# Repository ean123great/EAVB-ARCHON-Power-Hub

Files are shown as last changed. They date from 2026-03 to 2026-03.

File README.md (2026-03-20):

# EAVB ARCHON 15W Power Hub
**High-Efficiency DC-DC Step-Down Architecture with PMOS Protection**

Designed by **Elcyn Andrew V. Booc** | EAVB Electronics



The **ARCHON Power Hub** is a compact, industrial-grade power management module designed for autonomous robotics, IoT systems, and high-reliability embedded environments. Utilizing a 1.5 MHz switching frequency and the proprietary "Ocean Ground Strategy," ARCHON delivers up to 15W of continuous power with exceptional thermal stability and minimal EMI.

---

### Key Architectural Features
* **Zero-Drop Reverse Polarity Protection:** Utilizes an AO4407A P-Channel MOSFET instead of a standard Schottky diode, eliminating thermal dissipation and voltage drop at the input stage.
* **The "Ocean Ground Strategy":** A highly optimized SMD PCB layout utilizing extensive ground pours and thermal via stitching to turn the entire FR4 board into a passive heatsink.
* **High-Frequency Regulation:** Driven by the MP1584EN switching regulator operating at 1.5 MHz, allowing for extreme component density and rapid transient response.
* **Industrial Form Factor:** Exclusively utilizes Surface Mount Devices (SMD), including 0805 passives and SOIC-8 packaging, for a manufacturing-ready footprint.

---

### Absolute Maximum Ratings & Specifications

| Parameter | Specification | Notes |
| :--- | :--- | :--- |
| **Input Voltage Range** | 4.5V to 28V DC | Regulated |
| **Output Voltage** | 5.0V (Adjustable) | Tuned via precision resistor network |
| **Max Continuous Current** | 3A | Requires adequate airflow at max load |
| **Maximum Power Output** | 15W | |
| **Peak Efficiency ($\eta$)** | Up to 92% | Load dependent |
| **Switching Frequency** | 1.5 MHz | Reduces inductor size requirement |

---

### Repository Structure
* `/Hardware` - KiCad schematic (`.kicad_sch`), PCB layout (`.kicad_pcb`), and manufacturing Gerber files.
* `/Docs` - Official EAVB technical specifications, absolute maximum ratings, and theory of operation (PDF).

---

### Intellectual Property & Commercial Licensing
This hardware design is protected under the **CC BY-NC-SA 4.0** license. 
* **Non-Commercial Use:** Students, hobbyists, and researchers are free to study, build, and modify this architecture for personal or academic use, provided credit is given to **EAVB Electronics**.
* **Commercial Use:** Manufacturing this board for sale or integrating this architecture into a commercial product is strictly prohibited under this license.

> **For Commercial Manufacturing Rights:** > Please contact the Lead Architect at **eavb.electronics@gmail.com** for corporate licensing agreements.

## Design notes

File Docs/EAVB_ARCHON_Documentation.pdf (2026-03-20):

EAVB Electronics (2026) | ARCHON 15W HUB | Version 1.0
Document v1.0 | Elcyn Andrew V. Booc | March 2026

# ARCHON 15W POWER HUB: High-Efficiency DC-DC Converter & Distribution Node

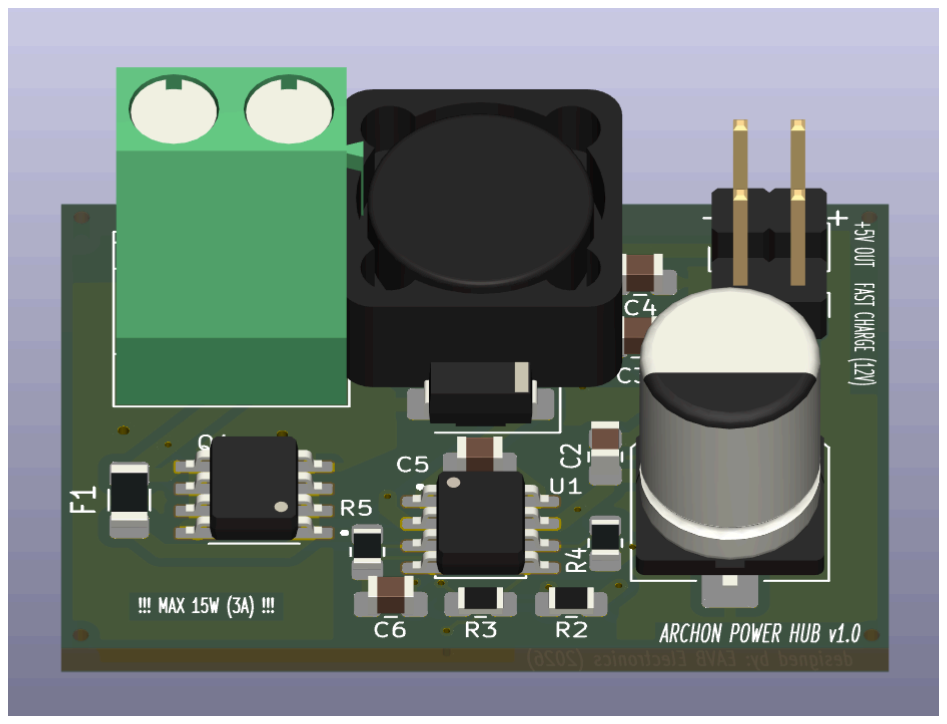
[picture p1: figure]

## GENERAL DESCRIPTION

The Archon Power Hub is a robust, high-efficiency synchronous switch-mode DC-DC step-down converter designed for precision voltage regulation and hardware protection. Centered around the MP1584EN high-frequency switching architecture, the Archon seamlessly steps down a 12V DC input to a heavily filtered, stable 5V output. Featuring hardware-level PMOS reverse-polarity shielding and a heavy copper thermal ground plane, the Archon delivers clean, low-noise power optimized for sensitive embedded electronics, microcontrollers, and prototyping environments.

## KEY FEATURES

- Optimized Power Delivery: 5V output at up to 3.0A continuous current (15W).
- Wide Input Range: 7.0V to 12.0V DC operational input.
- Hardware-Level Protection: Integrated P-Channel MOSFET (Q1) and Fuse (F1) for zero-drop reverse polarity and overcurrent protection.
- High-Frequency Switching: ~1.5 MHz programmable switching frequency minimizing external component size.
- Ultra-Low Ripple: Dual-stage parallel ceramic output filtering (C3, C4) for superior transient response.
- Versatile Distribution: Dual USB Type-C module headers and auxiliary Dupont outputs.
Document v1.0 | ARCHON 15W HUB | Page 1

## Electrical Characteristics & Ratings

Parameter | Symbol | Min | Typ | Max | Unit

ABSOLUTE MAXIMUM RATINGS

Input Supply Voltage | VIN | -0.3 | -- | 15.0 | V
Enable Pin Voltage | VEN | -0.3 | -- | 6.0 | V
Switch Node Voltage | VSW | -0.3 | -- | VIN + 0.3 | V
Maximum Junction Temperature | TJ(MAX) | -- | -- | 150 | °C
Storage Temperature Range | TSTG | -65 | -- | 150 | °C
RECOMMENDED OPERATING CONDITIONS
Input Operating Range | VIN | 7.0 | 12.0 | 12.0 | V
Regulated Output Voltage | VOUT | 4.90 | 5.00 | 5.10 | V
Continuous Output Current | IOUT | 0 | -- | 3.0 | A
Switching Frequency | fSW | -- | 1.5 | -- | MHz
Operating Ambient Temperature | TA | -40 | 25 | 85 | °C
SYSTEM PERFORMANCE & THERMAL
Quiescent Current (No Load) | IQ | -- | 1.0 | 1.5 | mA
Conversion Efficiency (VIN=12V, 2A) | η | -- | 92 | -- | %
Output Voltage Ripple | VRIPPLE | -- | 30 | 50 | mV
Thermal Resistance (Junction-to-Ambient) | θJA | -- | 50.0 | -- | °C/W
Document v1.0 | ARCHON 15W HUB | Page 2

## SYSTEM ARCHITECTURE & THEORY OF OPERATION

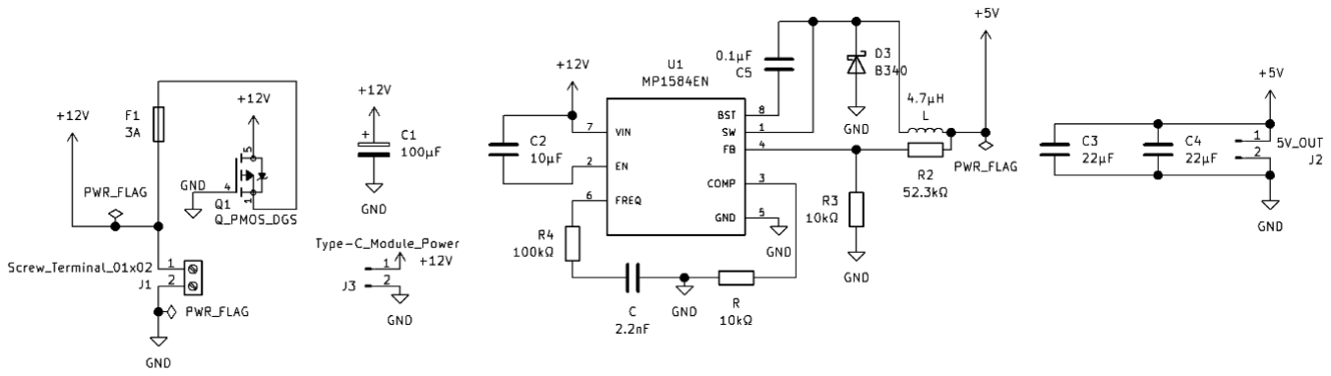
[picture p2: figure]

### 1. Input Protection Stage

Power enters via the J1 screw terminal and immediately passes through an overcurrent fuse (F1) and a P-Channel MOSFET (Q1). Unlike a standard blocking diode which wastes power through forward voltage drop, Q1 is configured as a low-RDS(on) reverse-polarity shield. If a power source is connected with reversed polarity, the gate-to-source voltage is neutralized, driving the PMOS into strict cut-off. This creates an immediate open circuit, protecting all downstream components with near-zero thermal loss during normal operation.

### 2. High-Frequency Step-Down Conversion

The core regulation is handled by U1 (MP1584EN). By utilizing a high switching frequency, the converter maintains greater than 90% efficiency while allowing the use of a highly compact 4.7µH surface-mount inductor (L2). The output voltage is strictly clamped to 5.0V via the precision feedback resistor network (R2, R3), which constantly samples the output node to dynamically adjust the internal duty cycle.

### 3. Switch Node & EMI Mitigation

To minimize electromagnetic interference (EMI), the "hot loop" comprising the U1 switch pin, inductor L2, and the Schottky catch diode (D3) is physically condensed. Trace lengths within this switching node are kept microscopic to reduce parasitic inductance and prevent the traces from acting as RF antennas.

### 4. Output Filtering & Distribution

Output power stability is guaranteed by placing two ceramic capacitors (C3 and C4) in parallel directly at the 5V output net. This parallel configuration drastically lowers the Equivalent Series Resistance (ESR) and Equivalent Series Inductance (ESL), acting as a high-speed shock absorber for high-frequency voltage ripples before the power is distributed to the Type-C and auxiliary headers.

Document v1.0 | ARCHON 15W HUB | Page 3

## PCB LAYOUT & THERMAL MANAGEMENT

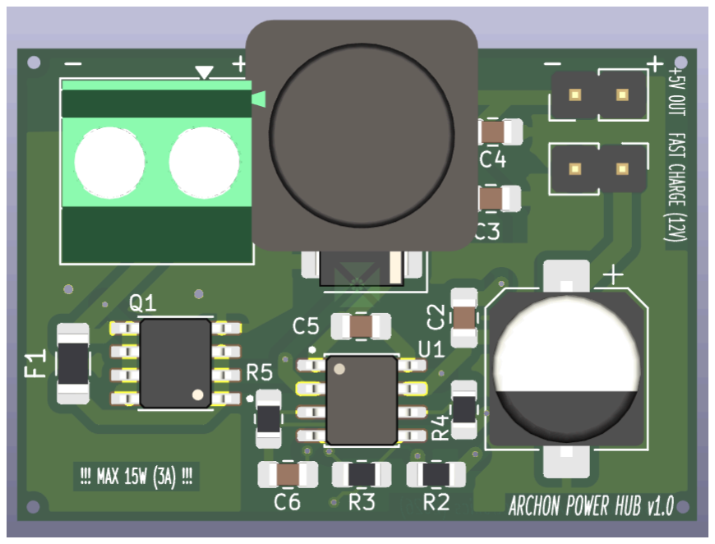
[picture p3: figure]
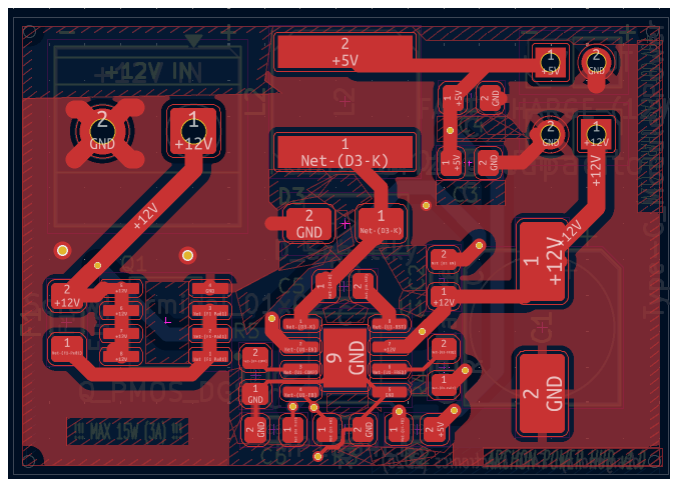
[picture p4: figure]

### 1. The Ocean Ground Strategy

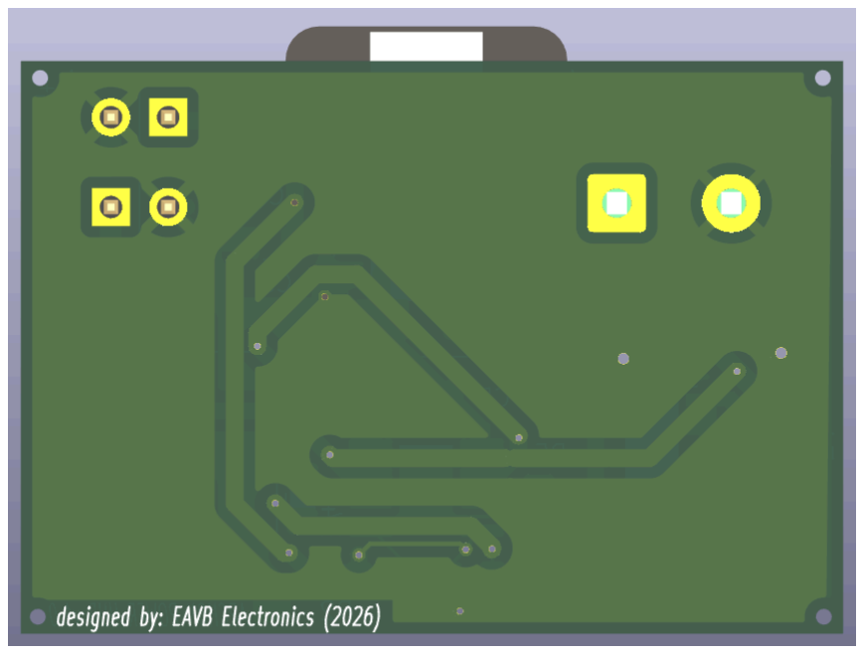
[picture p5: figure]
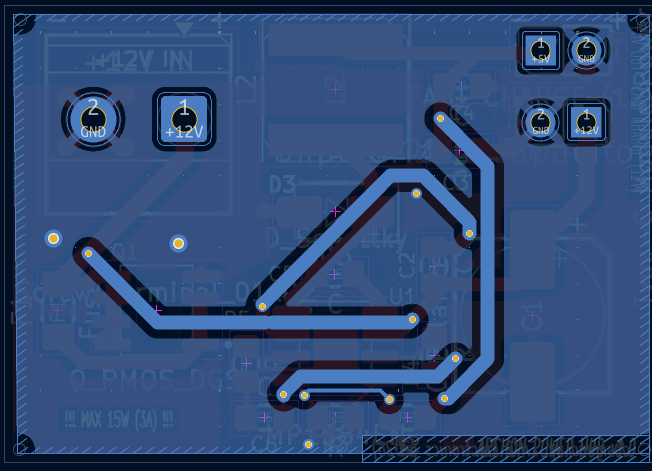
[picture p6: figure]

The Archon utilizes a continuous bottom-layer copper pour connected to the primary Ground net. This uninterrupted plane serves a dual purpose: it acts as a low-impedance return path for high-frequency switching currents (reducing ground bounce), and it functions as a massive passive heatsink.

### 2. Thermal Vias

To prevent thermal throttling within the MP1584EN silicon during continuous 3A loads, multiple thermal vias are stitched directly adjacent to the IC and inductor pads. These vias bridge the top-layer heat generators directly to the bottom "ocean" ground plane, radiating heat safely across the 75x50mm FR4 fiberglass substrate.

### 3. High-Current Routing

All primary power paths (VIN, Switch Node, and VOUT) are routed using oversized 0.8mm to 1.0mm copper traces. This exceeds standard ampacity requirements, ensuring minimal resistive voltage drops and virtually eliminating trace heating under peak load conditions.

Document v1.0 | ARCHON 15W HUB | Page 4

## Bill of Materials

Designator | Component Description | Value / Specification | Qty
U1 | High-Frequency Synchronous Buck Converter | MP1584EN | 1
Q1 | P-Channel Power MOSFET | AO4407A | 1
D3 | Schottky Barrier Rectifier Diode | B340 (3A, 40V) | 1
L2 | Shielded SMD Power Inductor | 4.7µH | 1
F1 | SMD Overcurrent Protection Fuse | 3.0A Fast Blow | 1
C1 | Electrolytic Input Filter Capacitor | 100µF (25V) | 1
C2 | Ceramic Input Bypass Capacitor (MLCC) | 10µF | 1
C3, C4 | Ceramic Output Filter Capacitor (MLCC) | 22µF | 2
C5 | Ceramic Bootstrap Capacitor | 0.1µF | 1
C6 | Ceramic Compensation Capacitor | 2.2nF | 1
R4 | Frequency Setting Resistor | 100kΩ | 1
R5 | Compensation Resistor | 10kΩ | 1
R2 | Top Feedback Resistor (5V Setting) | 52.3kΩ (1% Tolerance) | 1
R3 | Bottom Feedback Resistor | 10kΩ (1% Tolerance) | 1
J1 | 2-Pin Screw Terminal Block | 5.08mm Pitch | 1
J2 | 2-Pin Output Header (Dupont) | 2.54mm Pitch | 1
J3 | Type-C Power Delivery / Fast Charge Module | 12V Tolerant | 1
Document v1.0 | ARCHON 15W HUB | Page 5

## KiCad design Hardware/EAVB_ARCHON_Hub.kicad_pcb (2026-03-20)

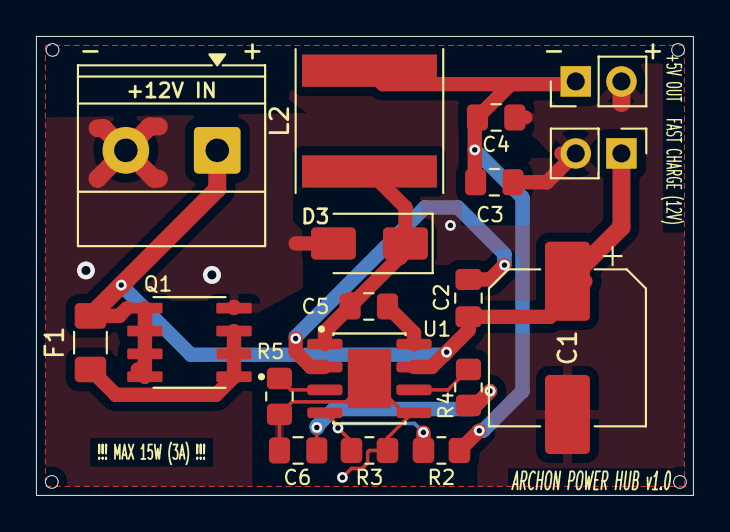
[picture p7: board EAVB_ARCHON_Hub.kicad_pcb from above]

Board: 2 copper layers, 36.5 x 25.5 mm, 18 parts (0 on the bottom side), 11 nets.

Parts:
+5V OUT: Conn_01x02_Pin; PinHeader_1x02_P2.54mm_Vertical
+12V IN: Screw_Terminal_01x02; TerminalBlock_Phoenix_MKDS-1,5-2-5.08_1x02_P5.08mm_Horizont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
C1: C_Polarized; CP_Elec_8x10.5
C2, C3, C4, C5, C6: C; C_0805_2012Metric_Pad1.18x1.45mm_HandSolder
D3: D_Schottky; D_SMA
F1: Fuse; Fuse_1206_3216Metric_Pad1.42x1.75mm_HandSolder
FAST CHARGE (12V): Type-C_Module_Power; PinHeader_1x02_P2.54mm_Vertical
L2: L; L_Taiyo-Yuden_NR-80xx
Q1: Q_PMOS_DGS; SOIC127P600X175-8N
R2, R3, R4, R5: R; R_0805_2012Metric_Pad1.20x1.40mm_HandSolder
U1: MP1584EN; SOIC127P600X170-9N

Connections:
+5V: +5V OUT.1, C3.1, C4.1, L2.2, R2.2
+12V: +12V IN.1, C1.1, C2.1, F1.2, FAST CHARGE (12V).1, Q1.5, Q1.6, Q1.7, Q1.8, U1.7 (VIN)
GND: +5V OUT.2, +12V IN.2, C1.2, C3.2, C4.2, C6.2, D3.2 (A), FAST CHARGE (12V).2, Q1.4, R3.2, R5.1, U1.5 (GND), U1.9 (GND)
unnamed: C6.1, R4.1
unnamed: C5.1, D3.1 (K), L2.1, U1.1 (SW)
unnamed: F1.1, Q1.1, Q1.2, Q1.3
unnamed: C5.2, U1.8 (BST)
unnamed: R5.2, U1.3 (COMP)
unnamed: C2.2, U1.2 (EN)
unnamed: R2.1, R3.1, U1.4 (FB)
unnamed: R4.2, U1.6 (FREQ)
